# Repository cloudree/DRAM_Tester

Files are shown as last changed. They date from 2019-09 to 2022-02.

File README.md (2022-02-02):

# DRAM_Tester
44256 / 4464 Dram Tester with Arduino

DRAM_Tester folder : KiCAD schematics and gerber files for arduino nano (or pro-mini)

DRAM_Testers : Arduino source

my blog posting (korean) :

https://blog.naver.com/cloudree/221388540394 

https://blog.naver.com/cloudree/221524164049

Good Luck!

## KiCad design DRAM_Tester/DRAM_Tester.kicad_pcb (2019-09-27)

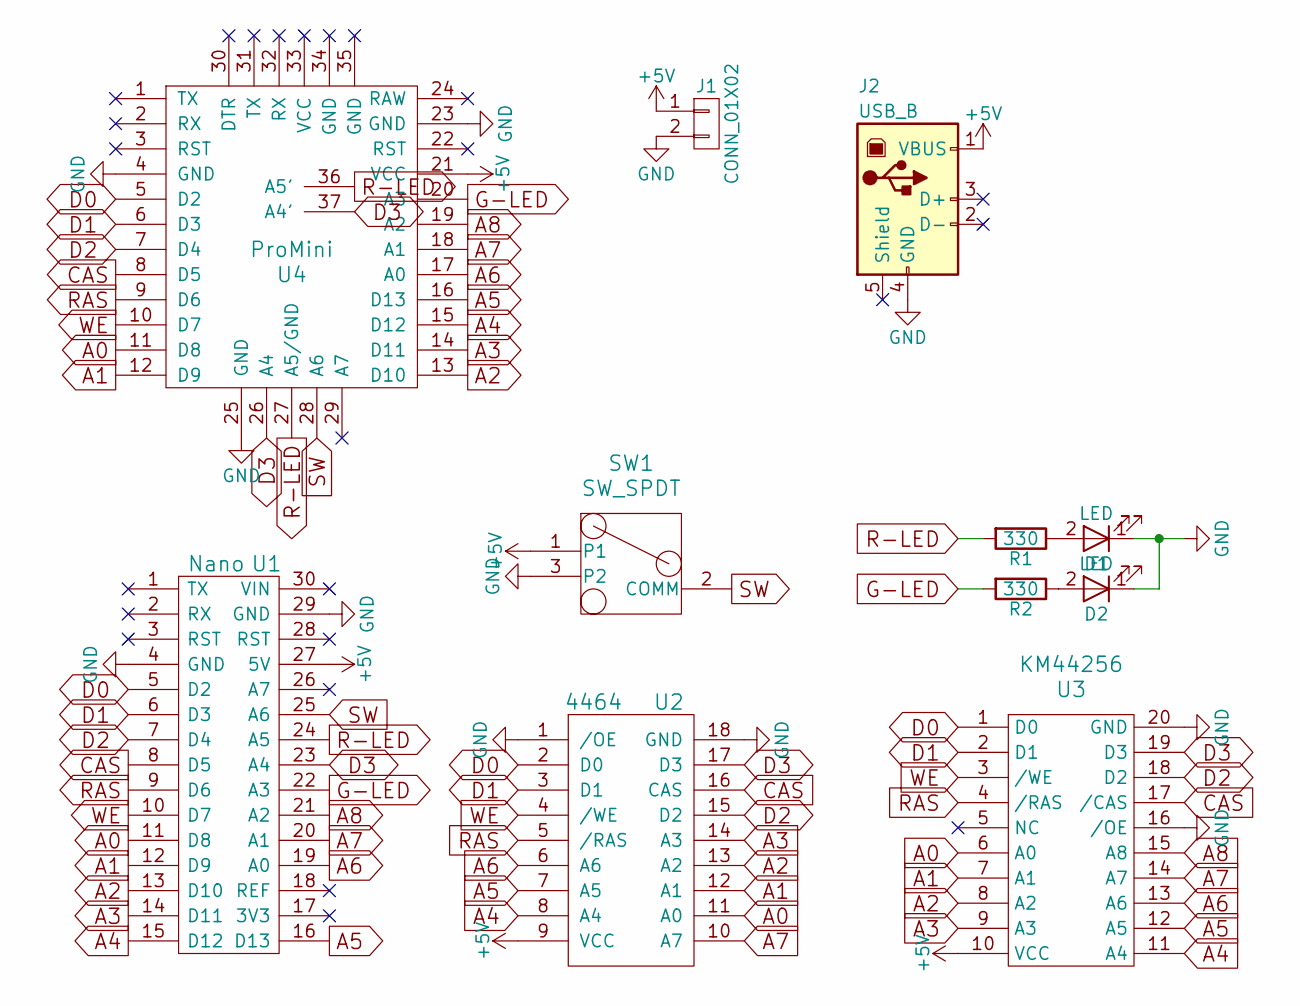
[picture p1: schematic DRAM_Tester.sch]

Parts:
D1, D2: LED; LED_Rectangular_W5.0mm_H2.0mm
J1: CONN_01X02; Pin_Header_Straight_1x02_Pitch2.54mm
J2: USB_B
R1, R2: 330; R_Axial_DIN0207_L6.3mm_D2.5mm_P10.16mm_Horizontal
SW1: SW_SPDT; Socket_Strip_Straight_1x03_Pitch2.54mm
U1: Nano; Arduino_Nano
U2: 4464; DIP-18_W7.62mm_Socket
U3: KM44256; DIP-20_W7.62mm_Socket
U4: ProMini; Arduino_Pro_Mini

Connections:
+5V: J1.1, J2.1 (VBUS), SW1.1, U1.27 (5V), U2.9 (VCC), U3.10 (VCC), U4.21 (VCC)
A0: U1.11 (D8), U2.11 (A0), U3.6 (A0), U4.11 (D8)
A1: U1.12 (D9), U2.12 (A1), U3.7 (A1), U4.12 (D9)
A2: U1.13 (D10), U2.13 (A2), U3.8 (A2), U4.13 (D10)
A3: U1.14 (D11), U2.14 (A3), U3.9 (A3), U4.14 (D11)
A4: U1.15 (D12), U2.8 (A4), U3.11 (A4), U4.15 (D12)
A5: U1.16 (D13), U2.7 (A5), U3.12 (A5), U4.16 (D13)
A6: U1.19 (A0), U2.6 (A6), U3.13 (A6), U4.17 (A0)
A7: U1.20 (A1), U2.10 (A7), U3.14 (A7), U4.18 (A1)
A8: U1.21 (A2), U3.15 (A8), U4.19 (A2)
CAS: U1.8 (D5), U2.16 (CAS), U3.17 (/CAS), U4.8 (D5)
D0: U1.5 (D2), U2.2 (D0), U3.1 (D0), U4.5 (D2)
D1: U1.6 (D3), U2.3 (D1), U3.2 (D1), U4.6 (D3)
D2: U1.7 (D4), U2.15 (D2), U3.18 (D2), U4.7 (D4)
D3: U1.23 (A4), U2.17 (D3), U3.19 (D3), U4.26 (A4), U4.37 (A4')
G-LED: R2.2, U1.22 (A3), U4.20 (A3)
GND: D1.1 (K), D2.1 (K), J1.2, J2.4 (GND), SW1.3 (P2), U1.4 (GND), U1.29 (GND), U2.1 (/OE), U2.18 (GND), U3.16 (/OE), U3.20 (GND), U4.4 (GND), U4.23 (GND), U4.25 (GND)
unnamed: D1.2 (A), R1.1
unnamed: D2.2 (A), R2.1
R-LED: R1.2, U1.24 (A5), U4.27 (A5/GND), U4.36 (A5')
RAS: U1.9 (D6), U2.5 (/RAS), U3.4 (/RAS), U4.9 (D6)
SW: SW1.2 (COMM), U1.25 (A6), U4.28 (A6)
WE: U1.10 (D7), U2.4 (/WE), U3.3 (/WE), U4.10 (D7)

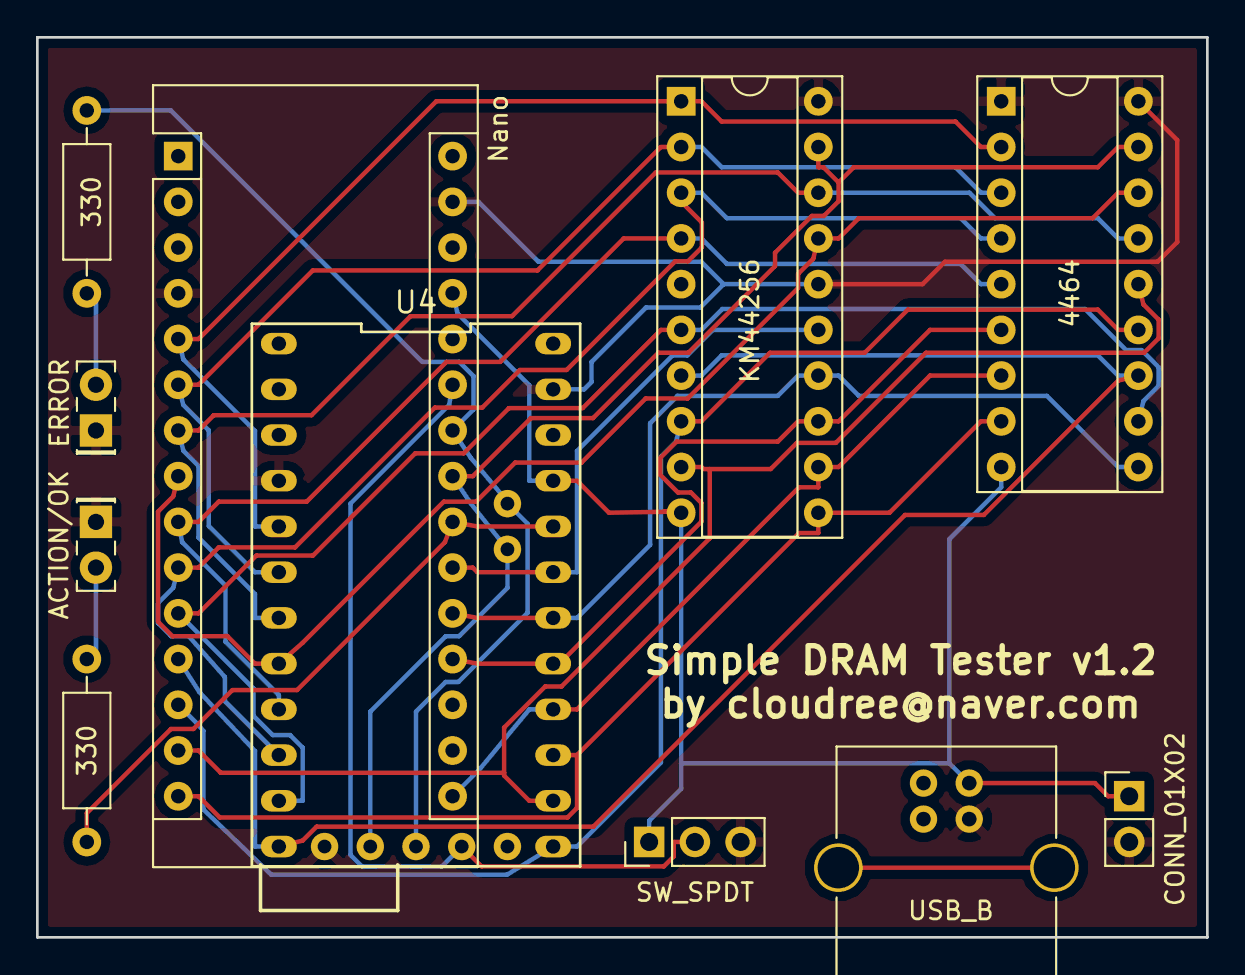
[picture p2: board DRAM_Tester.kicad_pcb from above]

Board: 2 copper layers, 65.0 x 50.0 mm, 11 parts (0 on the bottom side), 23 nets.

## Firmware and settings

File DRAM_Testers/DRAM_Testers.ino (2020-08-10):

//
// DRAM_Testers for 4464, 44256
// by cloudree@naver.com
//
//  4464      RAS CAS W     D0  D1  D2  D3    A0  A1  A2  A3  A4  A5  A6  A7
//  44256     RAS CAS W     D0  D1  D2  D3    A0  A1  A2  A3  A4  A5  A6  A7  A8    G-LED R-LED   SW
//  Arduino   D6  D5  D7    D2  D3  D4  A4    D8  D9  D10 D11 D12 D13 A0  A1  A2    A3    A5      A6
//

/* Simple DRAM tester
 * Chris Osborn <fozztexx@fozztexx.com>
 * http://insentricity.com/a.cl/252
 */

#include <Arduino.h>

#define _DEBUG
#define DATA_BITS         4
#define MAX_ADDR_BITS     10

int DATA[ DATA_BITS ] = { 2, 3, 4, A4 };

#define CAS             5
#define RAS             6
#define WE              7

#define G_LED           A3
#define R_LED		        A5
#define SW              A6

bool  g_is44256 = false;

inline void writePrepare()
{
    for( int i = 0; i < DATA_BITS; i ++ )
        pinMode( DATA[i], OUTPUT );
}

inline void writeData( int value )
{
    digitalWrite( DATA[0], value & 1 );
    digitalWrite( DATA[1], value & 2 );
    digitalWrite( DATA[2], value & 4 );
    digitalWrite( DATA[3], value & 8 );
}

inline void readPrepare()
{
    for( int i = 0; i < DATA_BITS; i ++ )
        pinMode( DATA[i], INPUT );
}

inline int readData()
{
    return digitalRead( DATA[0] )
       | ( digitalRead( DATA[1] ) << 1 )
       | ( digitalRead( DATA[2] ) << 2 )
       | ( digitalRead( DATA[3] ) << 3 );
}

inline int getAddrSize()
{
    return g_is44256 ? 10 : 8;
}

inline void setAddress( int row, int col )
{
    PORTB = row & 0x3f;
    PORTC = (PORTC & 0xf0) | (row >> 6) & 0x0f;
    digitalWrite(RAS, LOW);
    digitalWrite(WE, LOW);

    PORTB = col & 0x3f;
    PORTC = (PORTC & 0xf0) | (col >> 6) & 0x0f;
    digitalWrite(CAS, LOW);
    digitalWrite(WE, HIGH);
   
    digitalWrite(CAS, HIGH);
    digitalWrite(RAS, HIGH);
}

inline int getAddress( int row, int col )
{
    PORTB = row & 0x3f;
    PORTC = (PORTC & 0xf0) | (row >> 6) & 0x0f;
    digitalWrite(RAS, LOW);
  
    PORTB = col & 0x3f;
    PORTC = (PORTC & 0xf0) | (col >> 6) & 0x0f;
    digitalWrite(CAS, LOW);

    int val = readData( );
   
    digitalWrite(CAS, HIGH);
    digitalWrite(RAS, HIGH);
      
    return val;
}

void result( bool success )
{
    digitalWrite( G_LED, success ? HIGH : LOW );
    digitalWrite( R_LED, success ? LOW : HIGH );
#ifdef _DEBUG      
    Serial.println( success ? "\nSuccess" : "\nFailed" );
#endif
    while( 1 ) ;
}

void setup()
{  
#ifdef _DEBUG  
    Serial.begin( 57600 );
    Serial.println( "DRAM Tester by cloudree@naver.com");
#endif
      
    pinMode(CAS, OUTPUT);
    pinMode(RAS, OUTPUT);
    pinMode(WE, OUTPUT);
    digitalWrite(CAS, HIGH);
    digitalWrite(RAS, HIGH);
    digitalWrite(WE, HIGH);
  
    /* 10 is max address bits, even if chip is smaller */
    int mask = (1 << MAX_ADDR_BITS) - 1; 
    DDRB = mask & 0x3f;
    mask >>= 6;
    DDRC = mask & 0x0f;
    
    pinMode( G_LED, OUTPUT );
    pinMode( R_LED, OUTPUT );  
    digitalWrite( G_LED, LOW );
    digitalWrite( R_LED, LOW );

    pinMode( SW, INPUT );
    g_is44256 = analogRead( SW ) > 500;
    Serial.println( g_is44256 ? "Checking 44256" : "Checking 4464");
}

void loop()
{
    int count = 0;
    byte vals[] = { 0x5, 0xa };
    
    for( int col = 0; col < (1 << getAddrSize()); col ++ )
    {
        for( int row = 0; row < (1 << getAddrSize()); row ++ )
        {
            for( int idx = 0; idx < sizeof(vals); idx ++ )
            {
                if ( millis() % 1000 > 500 ) digitalWrite( G_LED, HIGH );
                byte val = vals[idx];
                writePrepare();
                writeData( val );
                setAddress( row, col );
                writeData( ~val );
                digitalWrite( G_LED, LOW );

                readPrepare();
                int ret = getAddress( row, col );
                if( ret != val )
                {
#ifdef _DEBUG                  
                    Serial.println( "Error, row=" + String(row) + ", col=" + String(col) + " : " + String(val) + "/" + String(ret) );
#endif                    
                    result( false );
                }
            }
        }
#ifdef _DEBUG        
        Serial.print(".");
#endif

        if( ++count > 64 ) 
        {
#ifdef _DEBUG          
            Serial.println("");
#endif            
            count = 0;
        }
    }
    result( true );
}

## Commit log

2019-09-27 Arduino Sources (Nano)
2019-09-27 KiCad Schematics and Gerber files
    [DRAM_Tester-B.Cu.gbr, DRAM_Tester-B.Mask.gbr, DRAM_Tester-Edge.Cuts.gbr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]
2020-08-10 Update DRAM_Testers.ino
    Fixed Address range. thanks for Greg McCarthy<greg@gjmccarthy.co.uk>
    [DRAM_Testers.ino]
